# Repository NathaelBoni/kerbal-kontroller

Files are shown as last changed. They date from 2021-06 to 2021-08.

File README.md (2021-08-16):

# KerbalKontroller
Repository for the source code, schematics and all things related to this custom controller for Kerbal Space Program

## Setup
Install the KSP Mod Simpit (currently using this [version](https://github.com/PBechon/KerbalSimpitRevamped/releases/tag/v2.0-alpha-6)).

It includes the Arduino library, which should be installed for the sketch to be properly compiled.

Upload the sketch in [this folder](https://github.com/Boni42/KerbalKontroller/tree/main/ArduinoKode) to the Arduino. The wiring schematic is available [here](https://github.com/Boni42/KerbalKontroller/blob/main/circuit.png).

Connect the controller before starting KSP.

On connection error, unplug the controller, restart the serial port and plug it again.

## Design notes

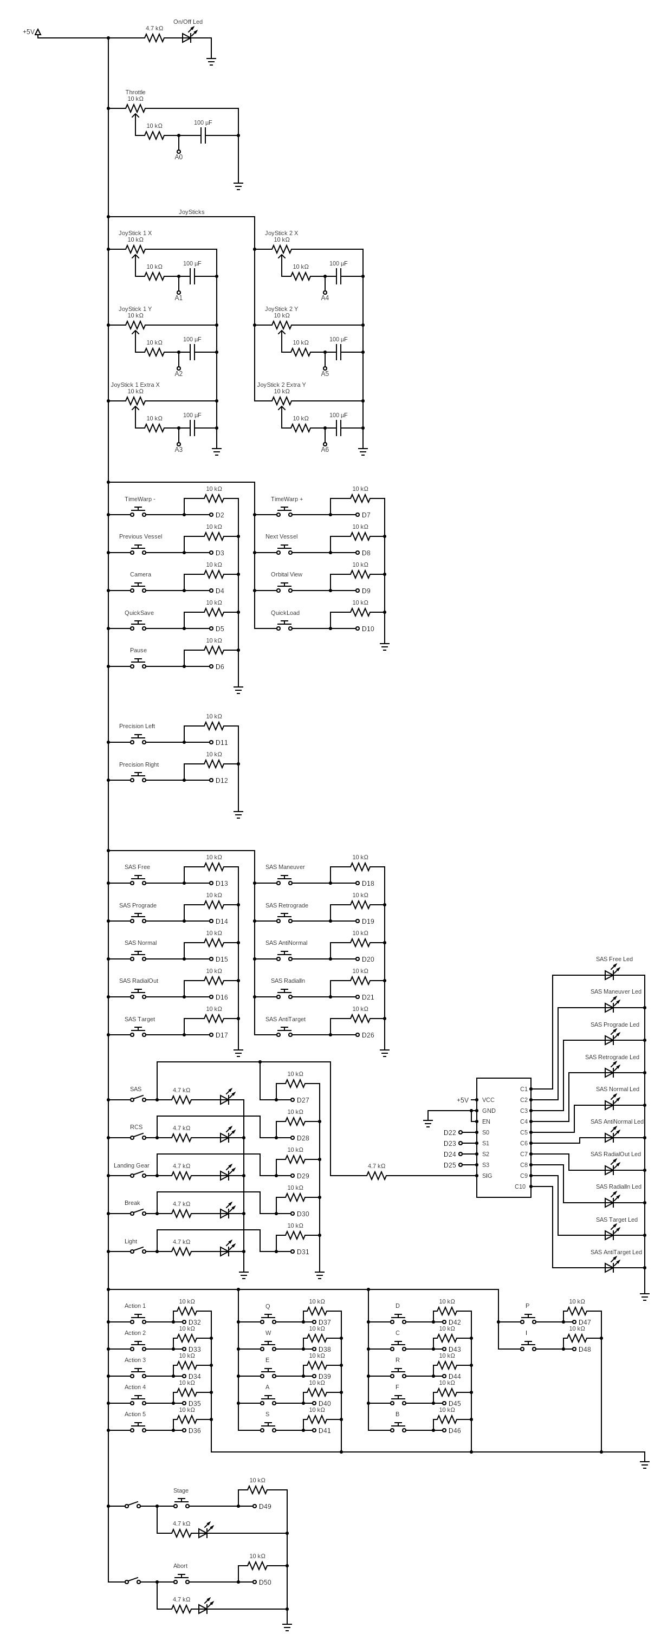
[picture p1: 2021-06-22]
circuit.png

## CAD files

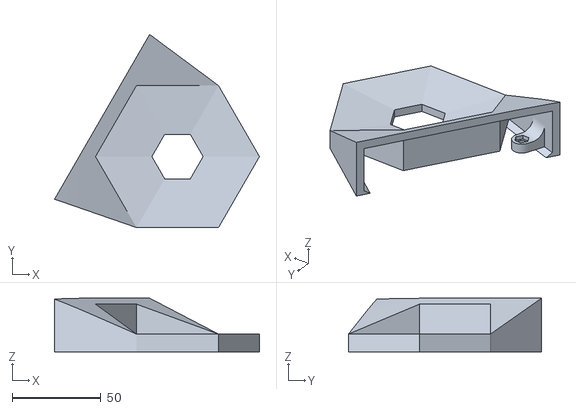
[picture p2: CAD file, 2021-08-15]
3DFiles/body/body_top_right_joy.stl
115.5 x 108.8 x 30.2

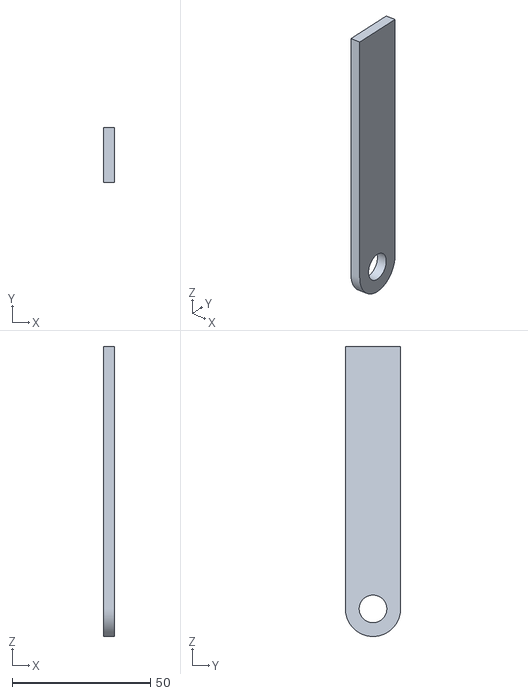
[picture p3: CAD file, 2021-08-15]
3DFiles/handle/axis_1.stl
3.90 x 20.0 x 105.0

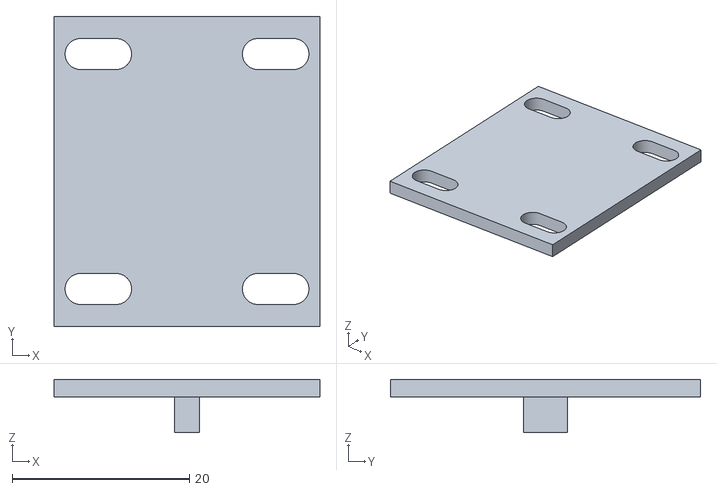
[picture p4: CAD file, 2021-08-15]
3DFiles/joystick/joy_case_right.stl
30.0 x 35.0 x 6.00

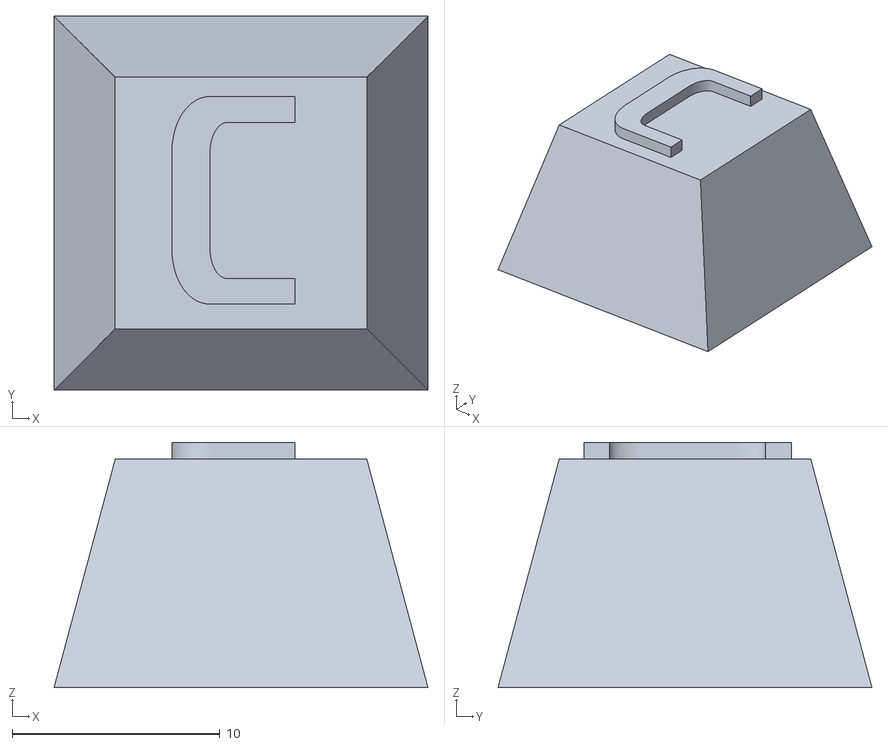
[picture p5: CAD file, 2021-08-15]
3DFiles/mech_keys/key_C.stl
18.0 x 18.0 x 11.8

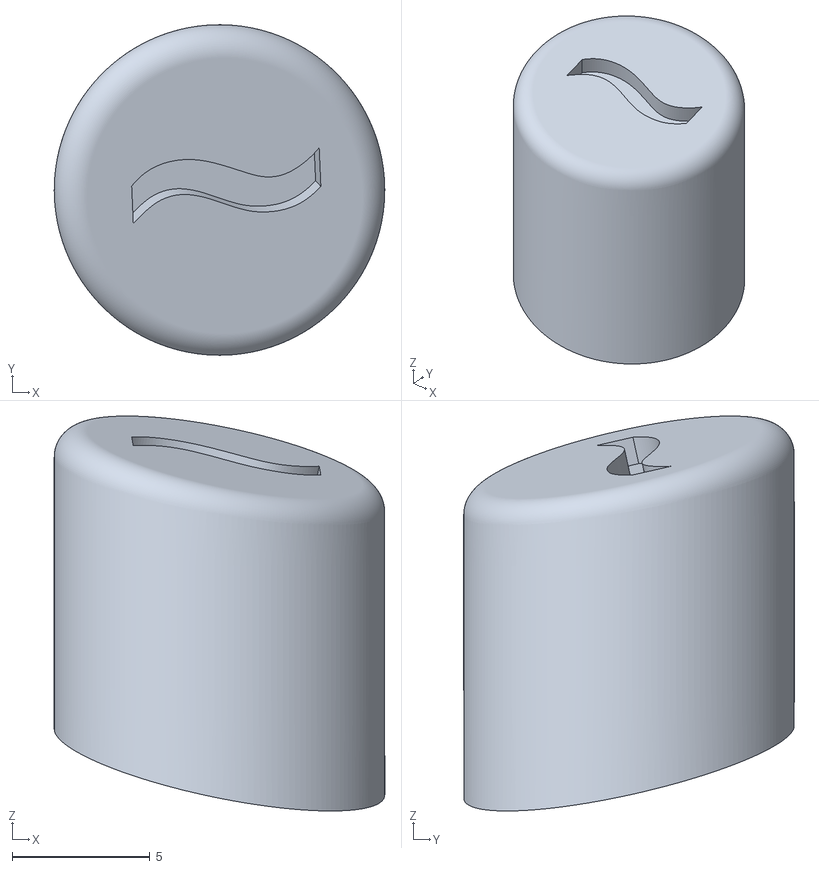
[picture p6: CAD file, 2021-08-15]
3DFiles/sas_buttons/free_button_top.stl
12.0 x 12.0 x 14.3

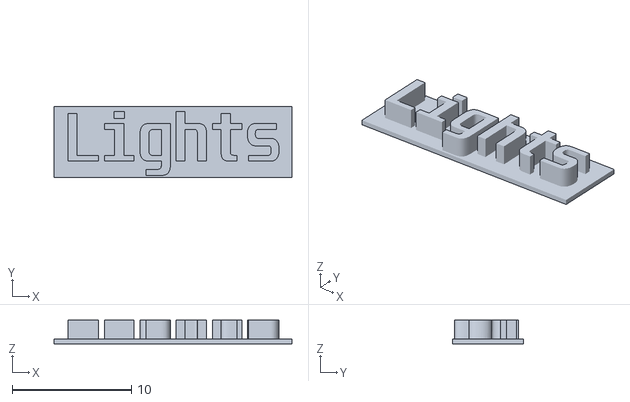
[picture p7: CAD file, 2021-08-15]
3DFiles/signs/sign_lights.stl
20.0 x 6.00 x 2.00

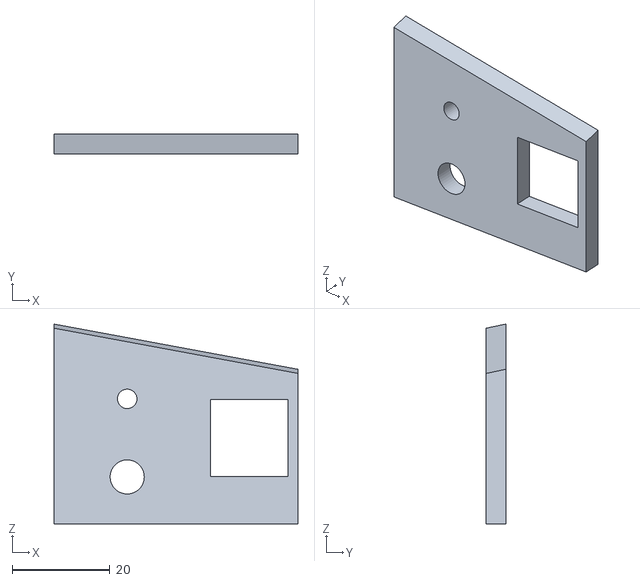
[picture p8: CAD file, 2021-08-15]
3DFiles/body/body_front_wall_sas.stl
50.0 x 4.00 x 41.0

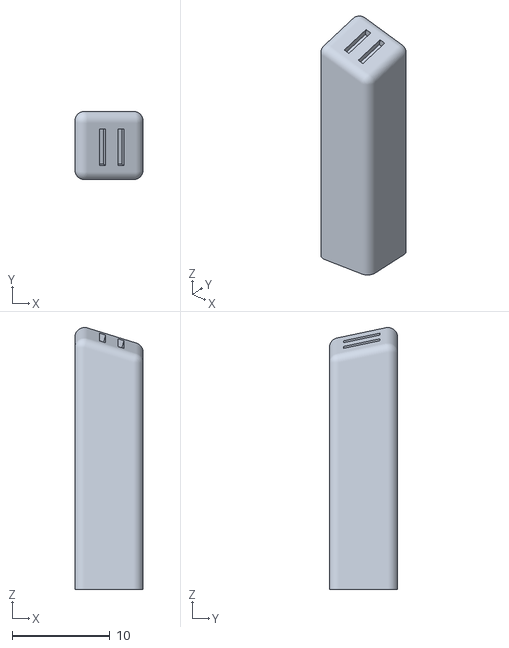
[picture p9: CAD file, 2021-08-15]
3DFiles/game_buttons/pause_button.stl
7.00 x 7.00 x 26.8

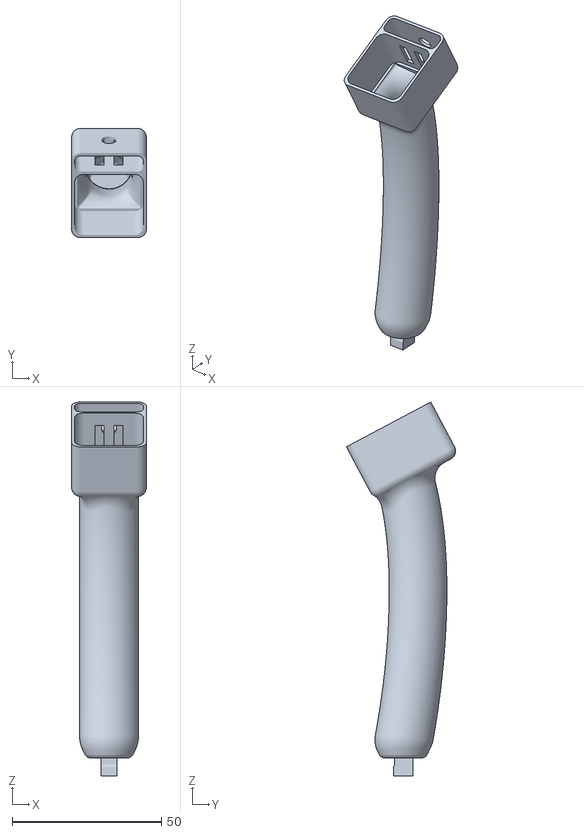
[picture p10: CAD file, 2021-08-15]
3DFiles/joystick/left_joystick.stl
25.0 x 36.6 x 125.2

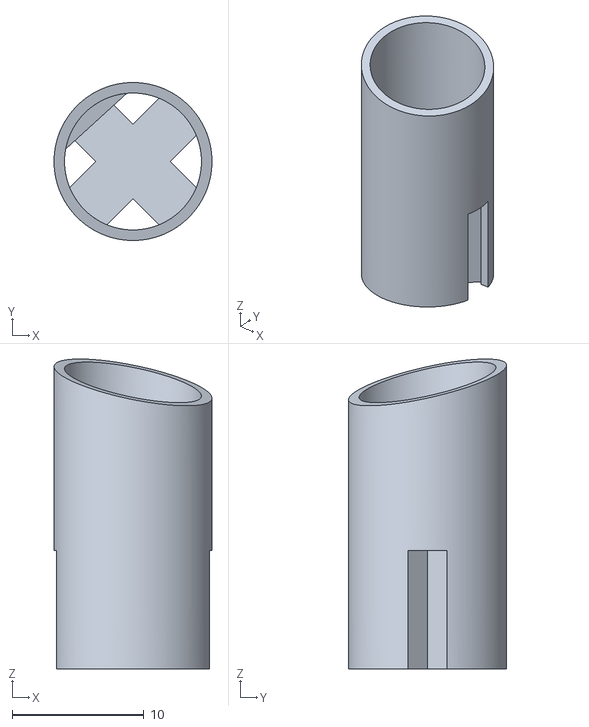
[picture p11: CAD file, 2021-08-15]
3DFiles/sas_buttons/normal_button.stl
12.0 x 12.0 x 23.5

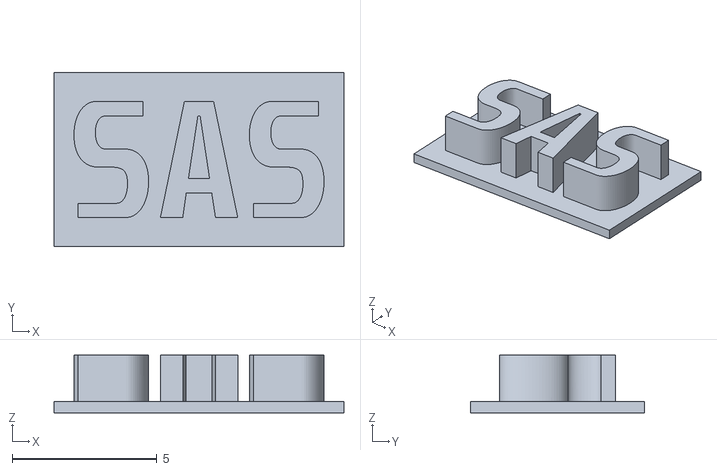
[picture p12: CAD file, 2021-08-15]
3DFiles/signs/sign_sas.stl
10.0 x 6.00 x 2.00

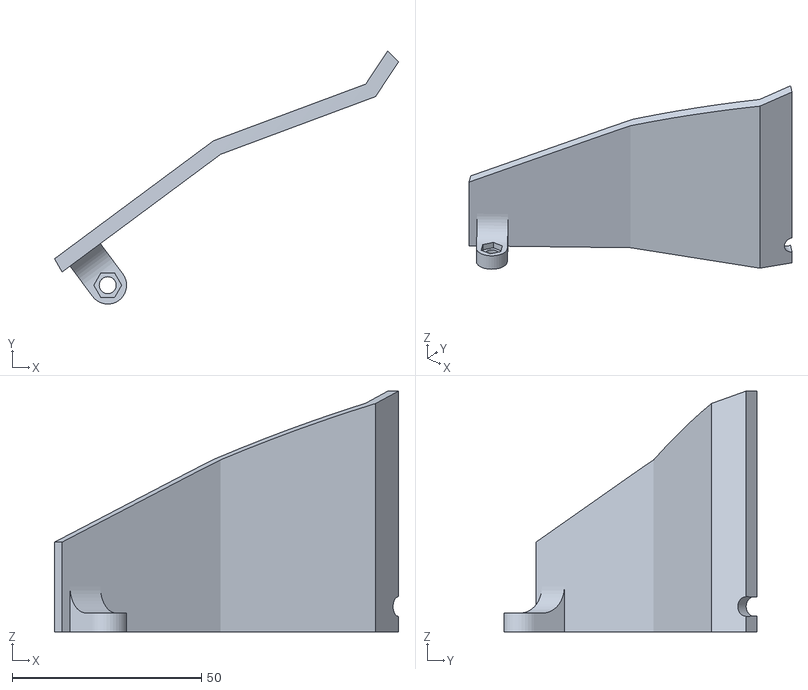
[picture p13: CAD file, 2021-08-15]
3DFiles/body/body_back_wall_mech.stl
91.0 x 67.0 x 63.7

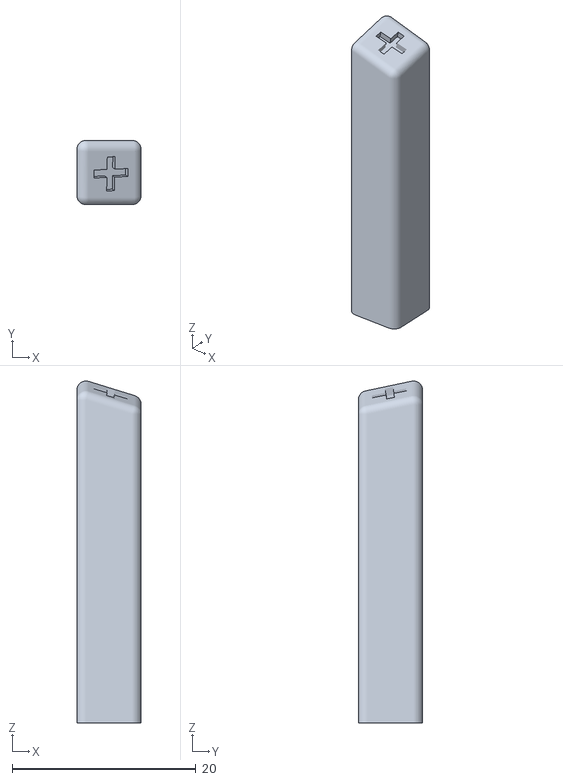
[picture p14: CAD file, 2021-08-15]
3DFiles/game_buttons/timewarp+_button.stl
7.00 x 7.00 x 37.2

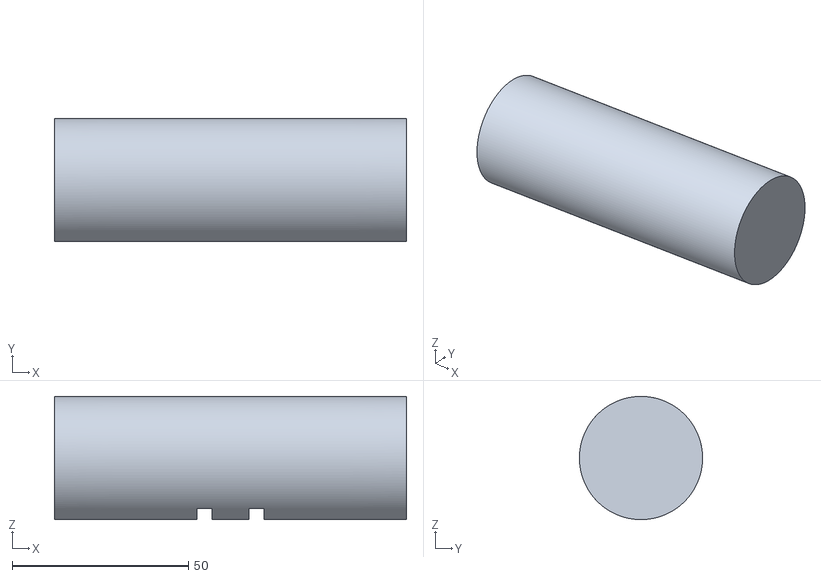
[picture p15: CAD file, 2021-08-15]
3DFiles/handle/handle.stl
100.0 x 35.0 x 35.0

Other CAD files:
3DFiles/mech_keys/key_P.stl
3DFiles/joystick/right_joystick.stl
3DFiles/mech_keys/key_B.stl
3DFiles/body/body_back_wall_game.stl
3DFiles/body/body_back_wall_sas.stl
3DFiles/body/body_bottom_center.stl
3DFiles/body/body_bottom_left.stl
3DFiles/body/body_bottom_right.stl
3DFiles/body/body_front_wall_game.stl
3DFiles/body/body_front_wall_mech.stl
3DFiles/body/body_top_center.stl
3DFiles/body/body_top_game_btn.stl
3DFiles/body/body_top_left_joy.stl
3DFiles/body/body_top_mech.stl
3DFiles/body/body_top_sas_btn.stl
3DFiles/body/body_top_switch.stl
3DFiles/body/body_wall_center.stl
3DFiles/body/body_wall_switch.stl
3DFiles/game_buttons/camera_button.stl
3DFiles/game_buttons/next_vessel_button.stl
3DFiles/game_buttons/orbital_view_button.stl
3DFiles/game_buttons/previous_vessel_button.stl
3DFiles/game_buttons/quickload_button.stl
3DFiles/game_buttons/quicksave_button.stl
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

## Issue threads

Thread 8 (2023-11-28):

What is the multiplexer component number?

askdesigners, 2023-11-28:
Hello! Love this simple controller project. I've been building it with my son but am a bit stumped by what the IC is in the schematic. I assume it's a multiplexer to drive the LEDs but not sure which. Any clarification would be super helpful. Thanks! Great work on this.

Oh, additionally it would be cool to have either a rendering of the full controller or a photo of what the final assembly looks like. I'm tempted to print the 3d parts but without knowing what it should look like I'm not sure how it should go together.

NathaelBoni, 2023-11-29:
Yes, I should've listed the parts somewhere, at least the model in the schematics. I have plans to update this repo, in the meanwhile, this is the datasheet for [CD74HC4067](https://www.ti.com/lit/ds/symlink/cd74hc4067.pdf).

About the 3D parts, I really don`t recommend them. I keep them here mostly for storage/backup. The entire structure is too finicky to put in place, I ended up using lots of glue and my solder iron to fuse the plastic together. It looked very nice but it's really hard. If you still wanna do it, I've uploaded two images here.
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

Also, something I should've done is use a 4-axis Joystick instead of those handles. There is one joystick at the base and another one on top, so you can maneuver in all directions with your hands and thumb, but it was very difficult to put it together, I really don't know how that is still working. One like this one from the image below should be much better.
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

Good luck, thank you for your interest!

Closed 2023-11-30.

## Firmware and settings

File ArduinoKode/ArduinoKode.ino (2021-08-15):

#include "KerbalSimpit.h"
#include "PinHelper.h"
#include "KerbalActions.h"
#include "ActionHelper.h"

void setup(){
  InitializePinsArray();
  SetPinMode();
  InitializeActions();
}

void loop(){
  if(gameStatus == EVA){
    ProcessKerbalWalking();
  }else{
    ReadActionButtons();
    if(flightType == SpaceShip){
      ProcessRotationSpaceShip();
      ProcessTranslation();
      ProcessThrottle();
    }else if (flightType == Plane){
      ProcessRotationPlane();
      ProcessTranslation();
      ProcessThrottle();
    }else if (flightType == Rover){
      ProcessRoverWheels();
      ProcessTranslation();
    }

    ReadActionButtons();
    ReadSASButtons();
    SetSASLed(currentSASMode);
    ReadSwitches();
    ReadAbortStage();
    ReadPrecisionButtons();
  }

  ReadKeys();
  ReadGameButtons();

  SimpitUpdate();
}

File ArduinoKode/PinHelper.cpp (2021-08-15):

#include <Arduino.h>
#include "KerbalSimpit.h"
#include "PinHelper.h"

unsigned long lastDebounce[ButtonsToDebounce];
byte currentState[ButtonsToDebounce], lastState[ButtonsToDebounce];
byte pins[ButtonsToDebounce];

void ReadInput(int pinIndex, boolean isSwitch, void (*callback)()){
    int reading = digitalRead(pins[pinIndex]);
  if (reading != lastState[pinIndex]) {
    lastDebounce[pinIndex] = millis();
  }

  if ((millis() - lastDebounce[pinIndex]) > DebounceDelay) {
    if (reading != currentState[pinIndex]) {
      currentState[pinIndex] = reading;
      if (currentState[pinIndex] == HIGH || isSwitch) {
        callback();
      }
    }
  }
  lastState[pinIndex] = reading;
}

void ReadButton(int pinIndex, void (*callback)()) {
  ReadInput(pinIndex, false, callback);
}

void ReadSwitch(int pinIndex, void (*callback)()) {
  ReadInput(pinIndex, true, callback);
}

void SetPinMode() {
  pinMode(LeftJoyStickX, INPUT);
  pinMode(LeftJoyStickY, INPUT);
  pinMode(ExtraLeftJoyStickX, INPUT);
  pinMode(RightJoyStickX, INPUT);
  pinMode(RightJoyStickY, INPUT);
  pinMode(ExtraRightJoyStickY, INPUT);
  pinMode(AnalogThrottle, INPUT);

  for (int i = 0; i < ButtonsToDebounce; i++) {
    pinMode(pins[i], INPUT);
  }

  pinMode(SASLedS0, OUTPUT);
  pinMode(SASLedS1, OUTPUT);
  pinMode(SASLedS2, OUTPUT);
  pinMode(SASLedS3, OUTPUT);
}

void SetSASLed(byte sasMode) {
  PORTA = (PORTA & 0xF0) | sasMode;
}

void InitializePinsArray() {
  pins[0] = PrecisionLeftButton;
  pins[1] = PrecisionRightButton;
  pins[2] = StageButton;
  pins[3] = AbortButton;
  pins[4] = LandingGearSwitch;
  pins[5] = BrakesSwitch;
  pins[6] = LightsSwitch;
  pins[7] = SASSwitch;
  pins[8] = RCSSwitch;
  pins[9] = KeyQ;
  pins[10] = KeyW;
  pins[11] = KeyE;
  pins[12] = KeyA;
  pins[13] = KeyS;
  pins[14] = KeyD;
  pins[15] = KeyC;
  pins[16] = KeyF;
  pins[17] = KeyB;
  pins[18] = KeyR;
  pins[19] = KeyP;
  pins[20] = KeyI;
  pins[21] = Action1Button;
  pins[22] = Action2Button;
  pins[23] = Action3Button;
  pins[24] = Action4Button;
  pins[25] = Action5Button;
  pins[26] = SASFreeButton;
  pins[27] = SASManeuverButton;
  pins[28] = SASProgradeButton;
  pins[29] = SASRetrogradeButton;
  pins[30] = SASRadialInButton;
  pins[31] = SASRadialOutButton;
  pins[32] = SASNormalButton;
  pins[33] = SASAntiNormalButton;
  pins[34] = SASTargetButton;
  pins[35] = SASAntiTargetButton;
  pins[36] = DecreaseTimeWarpButton;
  pins[37] = IncreaseTimeWarpButton;
  pins[38] = PreviousVesselButton;
  pins[39] = NextVesselButton;
  pins[40] = CameraCycleButton;
  pins[41] = OrbitalViewButton;
  pins[42] = QuickSaveButton;
  pins[43] = QuickLoadButton;
  pins[44] = PauseButton;
}

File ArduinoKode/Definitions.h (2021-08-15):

#ifndef _definitions_h
#define _definitions_h

#define MinOutput -32768
#define MaxOutput 32767
#define PrecisionMinOutput -10000
#define PrecisionMaxOutput 10000
#define MinThrottle 0
#define MaxThrottle 350
#define HalfInput 512
#define Deadzone 100

#define DebounceDelay 80
#define ButtonsToDebounce 45

#define LeftJoyStickX A3
#define LeftJoyStickY A2
#define ExtraLeftJoyStickX A1
#define RightJoyStickX A4
#define RightJoyStickY A5
#define ExtraRightJoyStickY A6
#define AnalogThrottle A0

#define PrecisionLeftButton 11
#define PrecisionRightButton 12

#define StageButton 49
#define AbortButton 50

#define SASSwitch 27
#define RCSSwitch 28
#define LandingGearSwitch 29
#define LightsSwitch 30
#define BrakesSwitch 31

#define KeyQ 37
#define KeyW 38
#define KeyE 39
#define KeyA 40
#define KeyS 41
#define KeyD 42
#define KeyC 43
#define KeyF 44
#define KeyB 45
#define KeyR 46
#define KeyP 47
#define KeyI 48

#define Action1Button 32
#define Action2Button 33
#define Action3Button 34
#define Action4Button 35
#define Action5Button 36

#define SASFreeButton 13
#define SASManeuverButton 18
#define SASProgradeButton 51
#define SASRetrogradeButton 19
#define SASRadialInButton 16
#define SASRadialOutButton 21
#define SASNormalButton 52
#define SASAntiNormalButton 20
#define SASTargetButton 17
#define SASAntiTargetButton 26

#define DecreaseTimeWarpButton 2
#define IncreaseTimeWarpButton 7
#define PreviousVesselButton 3
#define NextVesselButton 8
#define CameraCycleButton 4
#define OrbitalViewButton 9
#define QuickSaveButton 5
#define QuickLoadButton 10
#define PauseButton 6

#define SASLedS0 22
#define SASLedS1 23
#define SASLedS2 24
#define SASLedS3 25

#define OffLed 0x00
#define FreeLed 0x01
#define ManeuverLed 0x02
#define ProgradeLed 0x03
#define RetrogradeLed 0x04
#define NormalLed 0x05
#define AntiNormalLed 0x06
#define RadialInLed 0x07
#define RadialOutLed 0x08
#define TargetLed 0x09
#define AntiTargetLed 0x0A

#define InputA 0x41
#define InputB 0x42
#define InputC 0x43
#define InputD 0x44
#define InputE 0x45
#define InputF 0x46
#define InputI 0x49
#define InputV 0x56
#define InputM 0x4D
#define InputP 0x50
#define InputQ 0x51
#define InputR 0x52
#define InputS 0x53
#define InputW 0x57
#define Input1 0x31
#define Input2 0x32
#define Input3 0x33
#define Input4 0x34
#define Input5 0x35
#define InputSpace 0x20
#define InputShift 0xA0
#define InputCtrl 0xA2
#define InputESC 0x1B
#define InputPlus 0xBB
#define InputMinus 0xBD
#define InputF5 0x74
#define InputF9 0x78
#define InputF12 0x7B
#define InputComma 0xBC
#define InputDot 0xBE

#endif

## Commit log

2021-03-21 Add Arduino Driver package, create PoC
2021-03-21 Create facades for Arduino and KRPC connections
2021-03-27 Create all hardware reading methods using pin configuration
2021-03-28 Create hardware writing (led) methods
2021-03-29 Fix for invalid pin configuration
2021-04-02 Add missing SAS Maneuver button config
2021-04-02 Add camera cycle button
2021-05-09 Fix typo and add Maneuver led method
2021-05-16 Add SAS Modes led logic
2021-05-23 Set SAS mode led on switch action
2021-05-30 Add reading data from Arduino logic
2021-05-30 Add Arduino side of the project
2021-05-30 Add circuit schematic
2021-06-03 Use demux for SAS leds - update circuit and code
2021-06-14 Fix bitwise portA logic (SAS leds)
    [ArduinoKode.ino]
2021-06-22 Update circuit
2021-07-09 Add pin configuration settings
2021-08-15 Add 3d files (.stl)
    [abort.stl, action_1.stl, action_2.stl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]
